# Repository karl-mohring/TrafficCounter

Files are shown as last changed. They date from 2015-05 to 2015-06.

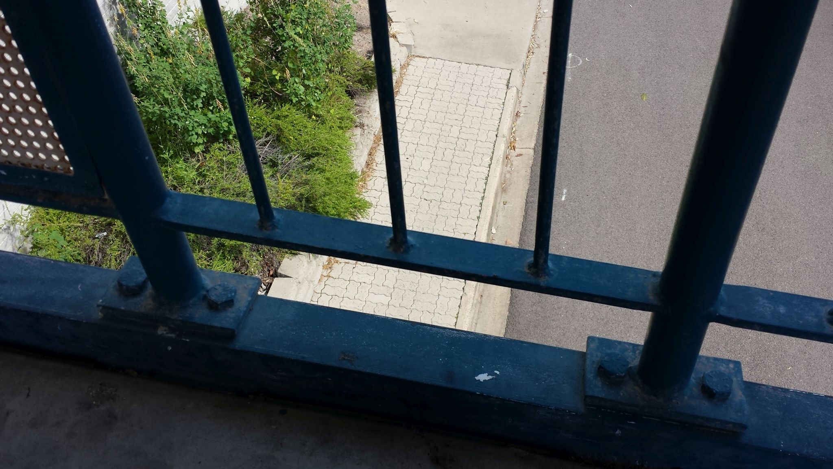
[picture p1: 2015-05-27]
CAD/Railing - 2015-05-19 11.09.42.jpg

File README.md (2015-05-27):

# TrafficCounter
Non-invasive traffic counter testbed for vehicular and pedestrian traffic. 
The testbed uses the Arduino platform, combined with low-cost and commonly available off-the-shelf sensors for ubiquitous traffic counting and classification for use inside Smart LED street lights. 

# Folders
##root
Contains the working code of the testbed, which is currently operating on the [WBoard Pro](http://imall.iteadstudio.com/im141125005.html). Functionally, the WBoard Pro is just an Arduino Mega, so either board will do. Or just change the pin assignments; what do I care?

##CAD
Graphical plans and 3D print files for mounting brackets and other peculiarities. 

##Libraries
Arduino Code libraries. What were you expecting?

##Pre-deployment Checks
Test code to check that each of the traffic sensors are functioning and calibrated before a recorded test or session.

##Tests
Test reports, recorded data, and archived code of platform deployments.

##Traffic Sink
Contains a Python script for data ingestion and uploading to Thingspeak. Change the API key in traffic_count_settings.py to suit your needs. My data is messy enough without other people injecting their own data...

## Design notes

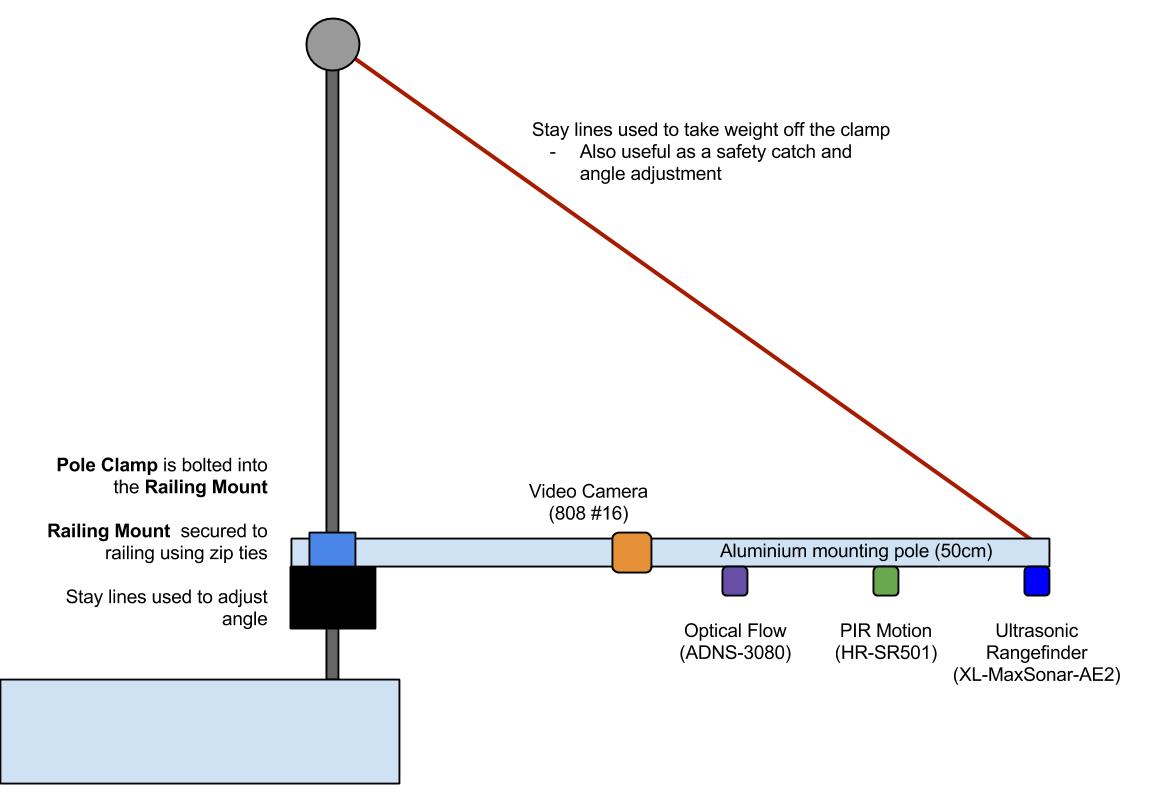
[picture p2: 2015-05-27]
CAD/TrafficCounter - Pole mounting.jpg

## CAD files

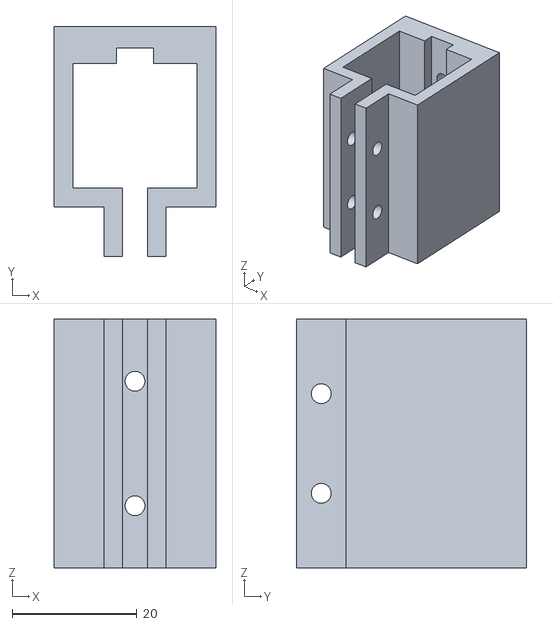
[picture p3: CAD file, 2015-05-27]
CAD/Pole clamp/Desk clamp - holder.stl
26.0 x 37.0 x 40.0

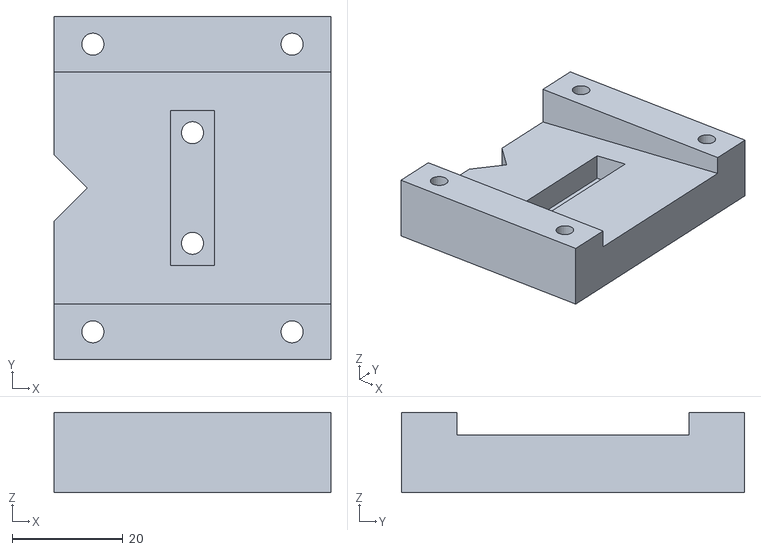
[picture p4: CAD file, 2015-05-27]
CAD/Railing Mount/Pole mount topv3 - Skewed.stl
50.0 x 62.0 x 14.5

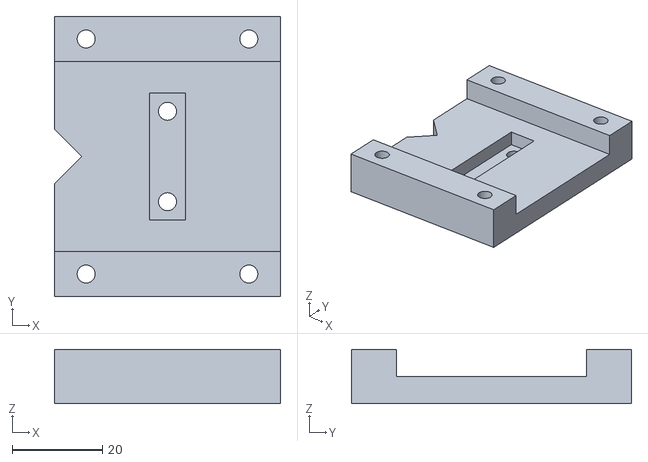
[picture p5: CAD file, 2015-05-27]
CAD/Railing Mount/Pole mount top.stl
50.0 x 62.0 x 12.0

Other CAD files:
CAD/Railing Mount/Pole mount top.skp
CAD/Railing Mount/Pole mount topv2.skp
CAD/Railing Mount/Pole mount topv3 - Skewed.skp

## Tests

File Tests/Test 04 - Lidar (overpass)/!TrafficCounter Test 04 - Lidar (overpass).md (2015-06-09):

Traffic Counter Testbed - 4th Test

Intro
=====

Aims
----

1) Test the new Lidar sensor to see if it more stable and accurate compared to the ultrasonic rangefinder (historically)

2) Test the new narrow-beam ultrasonic sensor 

Methodology
===========

Sensors
-------

- Ultrasonic rangefinder (Maxbotix XL-Maxsonar-AE2 1320)
- PIR motion sensor (HC-SR501)
- Optical flow sensor (ADNS3080)
- Keychain camera (808 #16)

Data recorder
-------------

- The ultrasonic, optical flow, and PIR sensors are periodically sampled by the WBoard Pro (Mega 2560) at a rate of 10Hz, 5Hz, and 1Hz respectively
- The keychain camera recorded constant video at a rate of 10 fps, with hard timestamps
- Whenever a traffic event is detected, all tracked data, including traffic counts from each of the sensors, sensor detection states, and other information is packaged and transferred across the USB serial link to the laptop, which is running a datalogger script
- The datalogger script adds a timestamp to each received entry and transfers the data into a log file
- Data entries are also uploaded to the Thingspeak service for real-time data monitoring over the web
- No local data storage occurs on the microcontroller board

Test location
-------------

- The second traffic sensing test was located at the pedestrian overpass outside building 34
- Sensors were secured inside a plastic container, which was then fixed to the railing directly above divide between the pedestrian footpath and roadway
- The container was angled so the sensors would be facing straight down into the roadway
- The container was secured at foot-level
- A nearby laptop was connected via USB to provide power to the sensors and also gather data for the duration of the test

Pre-Flight Checks
-----------------

Lidar
 - Baseline range of 518cm to the ground
 - No problems, seemed to detect just fine with a hand 30cm away from the sensor

OF
 - Sensor is now auto-adjusting to changes in light
 - can clearly see hand in frame from 50cm away
 - Motion not registered by sensor, but can see image at least...

Sonar
 - Baseline range of 626cm from the ground
 - readings are very twitchy, causing constant false detections
 - Readings appear to be defaulting to 626, rather than a baseline
 - Sensor is now operating off 3V3, which may be affecting its range

PIR
- Seems to be operating fine
- Hand gives a positive detection from 30cm away
-

Test Procedure
---------

1) The sensor container was secured to the outside railing of the pedestrian overpass
2) Power was supplied to the key chain camera using the laptop's USB port, and recording started well in advance of the sensor platform being turned on
3) Sensors were powered on and checked for reasonable input
4) Any necessary adjustments were applied before starting the datalogger script
- The optical flow sensor wiring became loose while securing the sensor platform to the railing and caused data to stop being transmitted by the sensor
    + The loose wire was secured at a fixed angle, which fixed the issue
- Took the lens cap off the optical flow sensor...
- The ultrasonic rangefinder was angled at various degrees to confirm readings were updating

Data Analysis
-------------

Results & Analysis
==================

Conclusions & Recommendations
=============================

UVD
---

PIR
---

Optical Flow
------------

Lidar
-----------------------

- Detection circle on ground appears to be a zone of 4cm radius
- Circle is not directly underneath the sensor, appearing approx. 1m to the right when looking down onto the road
- With a theoretical FOV of 3°, the detection circle should be approx. 25cm wide. 
- The detection circle is about right

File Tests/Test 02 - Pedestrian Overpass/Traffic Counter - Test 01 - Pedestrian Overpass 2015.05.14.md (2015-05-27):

Intro
=====

The second traffic counting test used various low-cost sensors to count both vehicular and pedestrian traffic in real time.

Aims
----
1) Test the ultrasonic rangefinder sensor in an open environment away from walls
2) Test the ultrasonic rangefinder with vehicular detection as well as pedestrian detection
3) Confirm or deny the functionality of optical flow sensing for traffic detection
4) Confirm that the PIR motion sensor was not suitable in outdoor environments

Methodology
===========

Sensors
-------

- Ultrasonic rangefinder (Maxbotix XL-Maxsonar-EZ2 1320)
- PIR motion sensor (DFRobotics PIR AM412)
- Optical flow sensor (ADNS3080)
- Keychain camera (808 #16)

Data recorder
-------------

- The ultrasonic, optical flow, and PIR sensors are periodically sampled by the WBoard Pro (Mega 2560) at a rate of 10Hz, 5Hz, and 1Hz respectively
- The keychain camera recorded constant video at a rate of 10 fps, with hard timestamps
- Whenever a traffic event is detected, all tracked data, including traffic counts from each of the sensors, sensor detection states, and other information is packaged and transferred across the USB serial link to the laptop, which is running a datalogger script
- The datalogger script adds a timestamp to each received entry and transfers the data into a log file
- Data entries are also uploaded to the Thingspeak service for real-time data monitoring over the web
- No local data storage occurs on the microcontroller board

Test location
-------------

- The second traffic sensing test was located at the pedestrian overpass outside building 34
- Sensors were secured inside a plastic container, which was then fixed to the railing directly above divide between the pedestrian footpath and roadway
- The container was angled so the sensors would be facing straight down into the roadway
- The container was secured at foot-level
- A nearby laptop was connected via USB to provide power to the sensors and also gather data for the duration of the test

Procedure
---------

1) The sensor container was secured to the outside railing of the pedestrian overpass
2) Power was supplied to the key chain camera using the laptop's USB port, and recording started well in advance of the sensor platform being turned on
3) Sensors were powered on and checked for reasonable input
4) Any necessary adjustments were applied before starting the datalogger script
- The optical flow sensor wiring became loose while securing the sensor platform to the railing and caused data to stop being transmitted by the sensor
    + The loose wire was secured at a fixed angle, which fixed the issue
- Took the lens cap off the optical flow sensor...
- The ultrasonic rangefinder was angled at various degrees to confirm readings were updating

5) Data was recorded and uploaded to Thingspeak using the datalogger script on the laptop
6) Recorded data was reviewed at the end of the test, with the option of using the recorded video feed to confirm numbers
 
Results & Analysis
==================

- Start time - 13:39:43
- Finish time- 15:14:21

- Running time - 1 hour 35 minutes

UVD
---

The ultrasonic sensor did not detect any pedestrians or vehicles at all during the test, and consistently returned a target distance between 60 cm and 90 cm. Despite a large volume of people walking underneath the sensor during the test, no events were registered by the sensor.

- The height of the pedestrian overpass is approximately 4 m above the road surface, meaning the sensor readings are clearly not accurate.
- The ultrasonic ping may be reflecting off the side of the overpass and giving false readings

PIR
---

Unlike the other sensors, the motion sensor recording an extremely high number of traffic events (1103 in total). The sensor was detecting movement when no pedestrians or vehicles were on the road.

- The sensor is much too sensitive for outdoor environments, where small changes are constantly occurring 

Optical flow
------------

No traffic events were detected by the optical flow sensor.

- The loose wiring is a concern and a possible cause for the optical flow sensor not detecting any events
- Optical flow operates on the basis that the entire frame moves a fixed amount. A single object moving across a fixed frame may not trigger the motion detection algorithm

Conclusions & Recommendations
=============================

UVD
---

The ultrasonic rangefinder is giving false readings, likely as a result of the ultrasonic ping reflecting off the bridge prematurely, instead of reflecting off the road surface. 
- A rangefinder with a narrow beam width (EZ4) may be used to replace the current sensor (that uses a medium beam width EZ2). 
- A second recommendation is to physically move the ultrasonic sensor further out and away from the edge of the overpass to avoid any reflected signals

> Order a Maxbotix XL-Maxsonar-EZ4 for further testing
> Determine the beam width of the ping on the ground for the next test
> Build a mounting arm for further tests on the overpass

PIR
---

For the second time, the motion sensor has given readings far higher than the number of actual traffic events. Motion detection is still a feasible method of traffic detection, but the sensor used in this test is far too sensitive to small changes in the environment to be of any use.
- Even in indoor environments, very small movements cause detection events.
- This particular PIR sensor does not have a configurable sensitivity. Replace the sensor with something that can be configured.

> Order a SE-10 or other PIR with configurable sensitivity and hardware timeout
> The sensor will need to be calibrated for outdoor environments

Optical Flow
------------

No traffic events were recorded by the sensor, despite having a clear view of the street below in full daylight. Connection problems may have caused the sensor to become unresponsive. Otherwise, the type of sensing performed by the sensor may not be suited to tracking the movement of individual objects.
The individual pixels of the sensor can be extracted to perform analysis on the raw data, but that would take more time than we have.
- Perform a connection check each time the sensor is read to ensure the reading is valid or if problems are occurring 
- The sensor should be re-calibrated and re-tested to ensure sensing conditions are fine

> Add code to check connectivity of the OF sensor - reflect disconnects in the data
> Perform some individual tests using the OF sensor

Further Recommendations
-----------------------

Given that no sensor has performed particularly well in the two traffic tests, it may be time to test another sensor type. Sparkfun's LIDAR lite uses laser ranging up to 40 m away. 

> Order a LIDAR from sparkfun

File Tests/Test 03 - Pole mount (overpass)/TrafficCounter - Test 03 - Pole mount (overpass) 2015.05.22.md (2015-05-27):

Traffic Counter Testbed - 3rd Test (Pole mounting)

Intro
=====

The third traffic counter test changed the mounting situation for the sensors from a shitty box to an outreach pole, not unlike those used by street light poles. A difference is that street light outreach poles aim to position the lamp closer to the centre of the roadway, while the sensor outreach pole is used to separate the traffic sensors away from any obstructions. The goals are different, but outreach poles help everyone.

Aims
----

1) Determine whether the outreach pole has fixed issues with the ultrasonic sensor
2) Run a test to ensure the optical flow sensor is actually working...
3) Test out the effectiveness of the new and adjustable PIR motion sensor

Methodology
===========

Sensors
-------

- Ultrasonic rangefinder (Maxbotix XL-Maxsonar-AE2 1320)
- PIR motion sensor (HC-SR501)
- Optical flow sensor (ADNS3080)
- Keychain camera (808 #16)

Data recorder
-------------

- The ultrasonic, optical flow, and PIR sensors are periodically sampled by the WBoard Pro (Mega 2560) at a rate of 10Hz, 5Hz, and 1Hz respectively
- The keychain camera recorded constant video at a rate of 10 fps, with hard timestamps
- Whenever a traffic event is detected, all tracked data, including traffic counts from each of the sensors, sensor detection states, and other information is packaged and transferred across the USB serial link to the laptop, which is running a datalogger script
- The datalogger script adds a timestamp to each received entry and transfers the data into a log file
- Data entries are also uploaded to the Thingspeak service for real-time data monitoring over the web
- No local data storage occurs on the microcontroller board

Test location
-------------

- The second traffic sensing test was located at the pedestrian overpass outside building 34
- Sensors were mounted to the underside of an aluminium outreach pole approximately 50cm long
- The pole was angled so the sensors would be facing straight down into the roadway
- The pole was secured at foot-level by a clamp and rope stay lines
- A nearby laptop was connected via USB to provide power to the sensors and also gather data for the duration of the test

Pre-Flight Checks
-----------------

UVD - The sensor output was checked for range to ensure the beam was not reflecting off the overpass or nearby surfaces. A manual reading was triggered by blocking the sensor with a hand

PIR - Similar to the ultrasonic sensor, the PIR sensor was manually triggered by moving a hand in front of the sensor. The PIR test does not have a cooldown timer, unlike the traffic counter firmware. Detection times and information is available in the test console.

Optical flow - To first calibrate the sensor, the RAW pixel data from the sensor is read and displayed on the laptop to ensure the frame is in focus. After calibration, the sensor's motion register is polled to check if motion has been detected by the sensor.

Procedure
---------

1) The sensor pole was secured to the outside railing of the pedestrian overpass
2) Power was supplied to the key chain camera using the laptop's USB port, and recording started well in advance of the sensor platform being turned on
3) Sensors were powered on and checked for reasonable input
4) Any necessary adjustments were applied before starting the datalogger script
- The optical flow sensor wiring became loose while securing the sensor platform to the railing and caused data to stop being transmitted by the sensor
    + The loose wire was secured at a fixed angle, which fixed the issue
- Took the lens cap off the optical flow sensor...
- The ultrasonic rangefinder was angled at various degrees to confirm readings were updating

5) Data was recorded and uploaded to Thingspeak using the datalogger script on the laptop

Data Analysis
-------------

1) Video data was reviewed to gain a comprehensive list of traffic information, including event times, traffic type (pedestrian, cyclist, vehicle), and whether or not a multiple event is occurring.
2) Count data was compared graphically between the actual video count and the other sensors, specifically:
    - PIR vs All traffic events (events; multiple events counted as one)
    - UVD vs Actual Vehicle traffic
    - New PIR events vs all traffic events (run-on events discarded)

Results & Analysis
==================

Over the course of the test, the video camera recorded a total of 50 combined traffic events (5 vehicles, 47 pedestrians, 5 cyclists, 1 scrub turkey). 

While the camera was focussed on the main detection area, the mounting and lens characteristics may mean that some events picked up the PIR sensor may not have been 'seen' by the camera.

UVD (and pole mount)
--------------------

Both during the pre-deployment check, and throughout the test, the ultrasonic rangefinder registered a baseline target distance of 792cm. While the range is likely not accurate (and beyond the sensors maximum rated range of 745cm), the ping does not appear to be reflecting off of the overpass edge. Range readings were less consistent in this test compared to previous deployments, as several pings were not returned, causing the range to read as 1024cm. 

During the pre-deployment check, several pedestrians walked underneath the sensor, but were not detected. However, a car driving on the road below was able to cause a detection to occur, but only on the incoming direction. The sensor did not detect the same car travelling in the opposite direction.

The ultrasonic sensor was not able to detect any pedestrian or cyclist traffic events during the recorded test, and only seemed to trigger when cars were on the road. Counting only vehicles, the UVD appeared to detect 3 of 5 vehicle events (not including the detection in the pre-deployment check) when compared to the video footage. The failed detection may be due to the sensor field of view looking at the footpath-road junction, rather than direction down onto the road, meaning the missing traffic events may have just been out of view of the sensor. 

The three positive vehicle detections by the ultrasonic rangefinder appear to occur a consistent 40 seconds before a vehicle detection event from the video, meaning there is likely a 40 second clock offset between the video camera, and the recording laptop.

1st vehicle - Not detected - Car was on the edge of the camera range, likely outside of the ultrasonic sensor detection area, cannot see roof in video

2nd vehicle - Detected - JCU buggy - reasonably close to the curb, large flat and high roof would assist detection

3rd vehicle - Detected - Sedan - reasonably close to curb, about the same as the buggy - hard to tell actual distances due to lens distortion

4th vehicle - Not detected - Far away from curb, cannot see roof in the video

5th vehicle - Detected - roof clearly visible from video, very close to the curb 

Vehicle detections caused the sensor to read range values from 532cm to 644cm, meaning car heights would have been 257cm and 144cm respectively. A vehicle height of 257cm is not entirely unreasonable for a 4wd or otherwise large vehicle, but only small sedans were observed during the test. The 144cm height is perfectly reasonable for the small cars observed during the test, which would indicate that cars were indeed being detected by the ultrasonic rangefinder. 

PIR
---

The PIR sensor performed as expected during the pre-deployment checks with the sensor firing only when a hand was moved in front of the sensor. Positive pedestrian detections occurred during the sensor check. The hardware motion cooldown reset after approximately 1.8 seconds. 

The software cooldown for the PIR sensor was set to reset after 2 seconds; not long after the hardware cooldown. The result of this low cooldown time is a large number of run-on events, where targets took longer than the cooldown time to cross the field of view, resulting in multiple traffic events being registered for the same target. Overall, 109 traffic events were captured by the PIR sensor, covering all types of traffic (the sensor is unable to distinguish between traffic types). A significant amount of these events were run-on motion events, where the motion event is still running even after the cooldown period has elapsed. The occurrance of run-on events is not surprising, considering pedestrians can take over 6 seconds to walk across the detection area, giving plenty of time for the sensor to trigger multiple times and causing an inflated traffic count. A workaround to eliminate these duplicate events was to discard traffic events where the previous sensor state was high (indicating a running detection event). Comparison of only 'new' detection events and video events showed a very high correlation between count timelines, as well as a very close total count (54 for PIR vs 50 for video).

Detection counts between PIR and video have very similar counts and times. The counts seem to diverge at points where multiple traffic events occur at once, indicating the PIR sensor may still be triggering twice for multiple events.

Very close (but separate) traffic events can be counted with video processing that cannot be detected by the PIR sensor because of its cooldown period.

The PIR count was consistently higher than the number of video events (apart from the start of the test), but also consistently lower than the actual traffic count (total number of pedestrians, cyclists, and vehicles)

Optical Flow
------------
 
 During the calibration for the optical flow sensor, the entire raw pixel data showed an entirely white frame that would only change when all light into the lens was blocked. Even the smallest amount of light would cause the sensor to completely white out. Changing the focal point of the lens did not affect the white-out. As this sensor has been used for outdoor navigation on multicopters, the sensor is clearly capable of outdoor usage, meaning the white-balance issues must be solvable.

 Furthermore, the sensor test, which is triggered by moving the entire sensor arm up, did not produce any motion detections. 

 While the sensor registered as "connected" during the pre-deployment check, the connection status changed to "disconnected" for the entirety of the recording period. Further checks in the lab with the same code did not experience this same sensor drop out.

Conclusions & Recommendations
=============================

UVD (and pole mount)
--------------------

Moving to the pole-mounted sensor deployment helped greatly in setting up and packing away sensors quickly and easily, allowing for consistent angling and overhang distance away from the side of the overpass. More importantly, the 40cm pole allowed for enough clearance for the ultrasonic rangefinder. Both in tethered and untethered tests (pole held out over road manually), moving the rangefinder away from the wall provided consistently and much more accurate readings. 

One possible issue with the current deployment setup is that the overpass is not level, and actually slopes at a 5° angle, meaning ultrasonic pings directed down towards the road will not hit and reflect perpendicularly. 
>The mounting bracket should be altered to correct for this slight angle.

The ultrasonic sensor was not able to detect any pedestrians during this test, but all detections occurred when a vehicle was on the road below, indicating that the rangefinder is able to detect vehicular traffic. However, vehicle detections only registered on the sensor when the car was very close to the road, almost directly under the sensor. 
>As the PIR sensor can detect movement over a wide area, the traffic counter should be placed closer to the middle of the road way to allow the ultrasonic sensor to detect traffic more accurately, while still allowing the PIR sensor to detect pedestrian traffic on the footpath.

The nature of ultrasonic sensor make the detection areas fairly unclear. 
>A buzzer should be added to the testbed to allow for rapid feedback on each of the sensors. Exact detection bounds can then be identified so the detection areas can be physically mapped out on the ground below for each of the sensors, and also picked up by the video footage. 

PIR
---

At the lowest sensitivity and shortest hardware cooldown, the PIR sensor was able to detect traffic events of all types with a great degree of accuracy (8% overshoot). However, the short sensor cooldown meant that many traffic events were counted twice. 
>The PIR cooldown time should be changed to more closely resemble the time it takes for a pedestrian to cross the detection boundaries for more accurate traffic counts.

Alternatively, only new traffic events should be counted to eliminate possible run-on events.

Optical Flow
------------
>Look into the datasheet to see if there's a way to fix the white balance, as the sensor is not currently able to output any useful data.

The optical flow sensor is not suitable at detecting motion in a fixed scenario, as the sensor operates by calculating movement over the entirety of the image, rather than individual objects moving through the frame. However, the raw output of the sensor allows for video image processing techniques to be used at a very low computational cost. The 900 pixel count is unsuitable for facial identification (which is a plus in this scenario), but is capable if identifying multiple objects at once, and categorising different moving objects, and calculating their approximate speed.

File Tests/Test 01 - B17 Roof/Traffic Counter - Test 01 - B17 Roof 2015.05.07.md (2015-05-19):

Intro
=====

The traffic counter test was used to test the accuracy of two sensors for non-invasive traffic detection. Ultrasonic vehicle detection uses the distance between the sensor and a distance target to determine whether or not traffic event is occurring. Normally, this distance will be from the sensor to the road surface if the sensor is deployed in an overhead position. Cars or pedestrians underneath will cause the sensor to register a shorter distance between the sensor and its target. This way, the sensor can determine the presence of an object in the beam path, and motion can be calculated using successive readings.

The second sensor uses Passive Infrared to monitor the surrounding environment and determine if any movement has occurred. All objects with temperatures above absolute zero radiate infrared energy that can be picked up the a sensor. The PIR sensor takes a snapshot of the surrounding area and checks for changes in infrared radiation. Any changes between snapshots indicate that something has moved.

Aim
---

1) Determine whether or not the ultrasonic rangefinder could be used to count pedestrian traffic when mounted at streetlight level
2) Determine whether or not the PIR sensor could be used to count pedestrian traffic when mounted at streetlight level

Methodology
===========

Sensors
-------

- Ultrasonic rangefinder (Maxbotix XL-Maxsonar-EZ2 1320)
- PIR motion sensor (DFRobotics PIR AM412)
- Keychain camera (808 #16)

Data recorder
-------------

- Both ultrasonic and PIR sensors were periodically sampled by the WBoard Pro (Mega 2560) at a rate of 5 Hz and 1 Hz respectively. The low sample rate with the PIR sensor is due to its long motion timeout of 3 seconds. That is, any movement picked up by the sensor would cause the device to advertise motion for 3 seconds.
- The keychain camera recorded constant video at a rate of 10 fps, with hard timestamps
- Traffic counts from each of the sensors was monitored and kept in local memory
- Data was written to an integrated SD card every 5 seconds
- The running sensor data was also transmitted to a nearby base station using an XBee transceiver
- The base station kept a log file of all received transmissions and uploaded the entries to a Thingspeak channel for monitoring over the web

Test location
-------------

- The sensor box was mounted on the roof of Building 17, on a pole overlooking the side entrance of the building
- Both sensors and the camera were pointed to capture the middle of the walkway (slightly off straight down)
- Power was supplied using a USB charger connected to a nearby power outlet on the roof of Building 17

Procedure
---------

1) The sensors and camera were secured at a fixed angle inside a container
2) The container was then secured to the mounting pole, then adjusted to achieve the desired angle
3) Power was switched on to the camera and microcontroller board to start sensor calibration and data recording
4) The nearby base station started receiving data soon afterwards and uploading the data online.

5) The sensors were left to record over the next 2 hours and 28 minutes
6) After the recording session, traffic events were mapped into time periods.
7) Actual pedestrian numbers were determined by reviewing the recorded video footage and mapped into the same time periods
8) Traffic counts, as well as event times were compared between the ultrasonic rangefinder, PIR sensor, and the video recording.

Results and Analysis
--------------------

Video
-----

Manually reviewing the recorded video footage revealed that a total of 80 people entered or exited the building over the couse of the test over 75 traffic events (some were double events). 
- Visual confirmation of traffic events was extremly valuable in gaining an accurate number of detection, as well as timestamps
- Video analysis also made double detections possible where other sensing methods may not perform as well
- The video was recorded to an onboard SD card, which allows the camera to be compact, but video can only be reviewed after recording has finished.
- Also, the video footage needed to be reviewed manually, which takes time and is prone to human error. Several video image processing programs exist for pedestrian and vehicle detection, but require more processing power that what is available in the test platform.

> Continue using manual video review for accurate traffic event coints

UVD
---

Over the course of the test, the ultrasonic sensor recorded 61 events. The ultrasonic and PIR traffic data did not have access to a real-time clock, meaning mapping needed to be approximated using base station timestamps and video events.
A direct comparison between the video counts and the ultrasonic detections shows a correlation between the two systems that diverges at the end. However, the correlation may be a result of erroneous range measurements.
According to the rangefinder, the sensor is located approximately 660 cm above the ground, which is not as high as expected. The beam may be reflecting off something on the wall.
- The ultrasonic rangefinder detected 61 individual traffic events, which is similar to the actual 75 events (61/75 events = 81.3% accuracy)
- While the count is similar, there is only a loose correlation between the video detection times and the ultrasonic detection times. Granted, there is an uncertainty in the timing offset between the video and the sensor data. Some ultrasonic detections appear entirely random, with no visible events that could trigger the sensor. Similarly, there are several traffic events that occur on video that are not detected by the ultrasonic sensor.
- At this point in time, there is no way of knowing whether the detections reported by the ultrasonic sensor are genuine or cause by erroneous readings, especially when the baseline height of the sensor is suspiciously low
- Another thing to consider is that the ultrasonic rangefinder was not inteded for pedestrian sensing, as the low cross-sectional area of pedestrians from an overhead perspective is low. Cars and other road vehicle exhibit a much larger cross-sectional area, which makes them more likely to be detected by the ultrasonic detector.

> Look for a better testing space for traffic testing

PIR
---

The PIR motion sensor detected 723 traffic events over the duration of the test, which was well in excess of the 75 actual events counted by the video footage. 
- While the sensor behaves as expected in an indoor lab condition, with motion alarms being triggered when objects are moving across the sensors field of view, the sensor behaves drastically different in outdoor environments. The sensitivity of the sensor caused the motion alarm to fire much more often. 
- One possibility is that small changes in lighting, such as those cast by shadows of surrounding vegetation, may have triggered the sensor to detect an event
- Another possible cause of the sensor's high detection rate is the altered lighting conditions compared to a lab environment. Direct sunlight is much brighter than indoor lighting. Perhaps there are peculiarities with this particular sensor and direct sunlight.

> Try the sensor again in a different location
> Find another PIR motion detector with an adustable sensitivity, so outdoor noise can be filtered
> Search the sensor's datasheet to see if there are and usage instructions for outdoor environments

Conclusions & Recommendations
=============================

Video
-----

Video monitoring proved to be extremely useful for counting traffic to verify the numbers presented by the other sensors. However, automating the footage review process is computationally intensive, and cannot be performed by the sensor platform hardware. Video image processing should still be used in the field of testing, but cannot be used for actual traffic sensing without using a much more powerful processor to handle the computational load.

UVD
---

The sensor output needs to be confirmed as correct through more testing.
Another testing location may be needed to better replicate the conditions found on streetlights with open spaces away from wall surfaces. 

PIR
---

Although the final traffic count registered b the motion sensor far exceeded the actual number of traffic events, motion sensing has been used by many pedestrian sensing effors in the past. Adjustable sensitivity, as well as appropriate lensing may be needed to handle the imitations that PIR sensors face when deployed in outdoor environments.

This test was the first outdoor deployment of the traffic sensor suite. The location, while not necessarily typical of a street light deployment, presented many challenges that would be present in an outdoor environment, including large nearby surfaces, and constantly changing environments.

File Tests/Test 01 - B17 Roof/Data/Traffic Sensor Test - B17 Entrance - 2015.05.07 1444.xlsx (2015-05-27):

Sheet: RAW
Traffic |  | counter
Rangefinder |  | baseline | 661 | cm | Variance | 0cm
************
 | count_uvd | 3 | count_pir | 1 | range | 32 | pir_status | FALSE | time | 13316 | entry_num | 1
 | count_uvd | 3 | count_pir | 2 | range | 662 | pir_status | TRUE | time | 18316 | entry_num | 2
 | count_uvd | 3 | count_pir | 3 | range | 662 | pir_status | TRUE | time | 23316 | entry_num | 3
 | count_uvd | 3 | count_pir | 4 | range | 664 | pir_status | TRUE | time | 28316 | entry_num | 4
 | count_uvd | 3 | count_pir | 5 | range | 664 | pir_status | FALSE | time | 33316 | entry_num | 5
 | count_uvd | 7 | count_pir | 5 | range | 662 | pir_status | FALSE | time | 38316 | entry_num | 6
 | count_uvd | 8 | count_pir | 5 | range | 97 | pir_status | FALSE | time | 44050 | entry_num | 7
 | count_uvd | 11 | count_pir | 6 | range | 134 | pir_status | TRUE | time | 48316 | entry_num | 8
 | count_uvd | 12 | count_pir | 6 | range | 661 | pir_status | FALSE | time | 53316 | entry_num | 9
 | count_uvd | 14 | count_pir | 6 | range | 790 | pir_status | FALSE | time | 58316 | entry_num | 10
 | count_uvd | 16 | count_pir | 7 | range | 662 | pir_status | TRUE | time | 63316 | entry_num | 11
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

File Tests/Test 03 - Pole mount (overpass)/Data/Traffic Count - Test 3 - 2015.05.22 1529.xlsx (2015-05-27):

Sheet: RAW
2015-05-22 | 15:29:20 | 503 | - | ERROR | - | Serial | port | [COM5] | cannot | be | opened | :(
2015-05-22 | 15:30:23 | 414 | - | ERROR | - | Serial | port | [COM3] | cannot | be | opened | :(
2015-05-22 | 15:30:39 | 168 | - | INFO | - | Incoming | packet: | u'count_pir': | 0 | u'of_dy': | 0 | u'count_uvd': | 0 | u'of_dx': | 0 | u'count_of': | 0 | u'range': | 787 | u'version': | 2 | u'of_status': | FALSE | u'pir_status': | FALSE | u'id': | u'trafficCount' | u'of_connected': | False}
2015-05-22 | 15:31:22 | 142 | - | INFO | - | Incoming | packet: | u'count_pir': | 1 | u'of_dy': | 0 | u'count_uvd': | 0 | u'of_dx': | 0 | u'count_of': | 0 | u'range': | 788 | u'version': | 2 | u'of_status': | FALSE | u'pir_status': | FALSE | u'id': | u'trafficCount' | u'of_connected': | True}
2015-05-22 | 15:31:25 | 171 | - | INFO | - | Incoming | packet: | u'count_pir': | 2 | u'of_dy': | 0 | u'count_uvd': | 0 | u'of_dx': | 0 | u'count_of': | 0 | u'range': | 782 | u'version': | 2 | u'of_status': | FALSE | u'pir_status': | TRUE | u'id': | u'trafficCount' | u'of_connected': | True}
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

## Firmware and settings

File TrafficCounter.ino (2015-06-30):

#include <LIDARduino.h>
#include <ADNS3080.h>
#include <SPI\SPI.h>
#include <ProgmemString.h>
#include <StraightBuffer.h>
#include <Logging.h>
#include <JsonParser.h>
#include <JsonGenerator.h>
#include <Maxbotix.h>
#include <SimpleTimer.h>
#include <CommandHandler.h>

#include "config.h"

using namespace ArduinoJson::Generator;

const int TRAFFIC_COUNTER_VERSION = 5;

//////////////////////////////////////////////////////////////////////////
// Traffic Counter
// 
// Uses non-invasive sensors to count vehicular and pedestrian traffic 
// from a distance. 
//
//////////////////////////////////////////////////////////////////////////


//////////////////////////////////////////////////////////////////////////
// Config


// Rangefinder
Maxbotix rangeSensor(RANGEFINDER_AN_PIN, Maxbotix::AN, Maxbotix::XL);
int rangeBaseline;

// Lidar
LIDAR_Lite_PWM lidar(LIDAR_TRIGGER_PIN, LIDAR_DETECT_PIN);
int lidarBaselineRange;

// PIR motion
bool motionDetected;
long timeOfLastMotion;

// Optical Flow
AP_OpticalFlow_ADNS3080 flowSensor(OPTICAL_FLOW_CHIP_SELECT_PIN, 0);
int8_t flow_dx;
int8_t flow_dy;

// Timers
SimpleTimer timer;
int rangeTimerID = -1;
int motionTimerID = -1;
int flowTimerID = -1;
int lidarTimerID = -1;

// Buzzer stuff
int beepCount = 0;
int maxBeeps = 0;

// Data storage
JsonObject<13> trafficEntry;
StraightBuffer sendBuffer(SEND_BUFFER_SIZE);

// Serial commands
char _commandCache[COMMAND_CACHE_SIZE];
CommandHandler commandHandler(_commandCache, COMMAND_CACHE_SIZE);

long entryNumber;
bool linuxBusy;


//////////////////////////////////////////////////////////////////////////
// Arduino Functions
//////////////////////////////////////////////////////////////////////////

/**
* Startup code - Run once
*/
void setup()
{
	startYunSerial();
	Log.Info(P("Traffic Counter - ver %d"), TRAFFIC_COUNTER_VERSION);

	// Start up sensors
	startBuzzer();
	startSensors();
	addSerialCommands();

}

/**
* Main loop - run forever
*/
void loop()
{
	timer.run();
	checkSerial();
}


//////////////////////////////////////////////////////////////////////////
// User Functions
//////////////////////////////////////////////////////////////////////////

//////////////////////////////////////////////////////////////////////////
// Yun Serial

/**
* Set up the Arduino-Linux serial bridge
* Serial output from the Arduino is disabled until the Yun has finished booting
*/
void startYunSerial(){

	// Set up the handshake pin
	pinMode(YUN_HANDSHAKE_PIN, INPUT_PULLUP);
	pinMode(LED_BUILTIN, OUTPUT);

	// Check the initial state of the handshake pin (LOW == Ready)
	delay(YUN_BOOT_DELAY);
	_bootStatusChange();

	Serial1.begin(SERIAL_BAUD);

	// Listen on the handshake pin for any changes
	attachInterrupt(4, _bootStatusChange, CHANGE);
}

/**
* Check the boot status of the Yun
*/
void _bootStatusChange(){
	linuxBusy = digitalRead(YUN_HANDSHAKE_PIN);
	digitalWrite(LED_BUILTIN, linuxBusy);

	// Disable log output until Linux boots
	if (linuxBusy){
		Log.Init(LOG_LEVEL_NOOUTPUT, &Serial1);
	}
	else{
		Log.Init(LOGGER_LEVEL, &Serial1);
	}
}

/**
* Enable and configure the sensor suite for reading
*/
void startSensors(){
	trafficEntry[ID] = "trafficCount";
	trafficEntry[VERSION] = TRAFFIC_COUNTER_VERSION;

	trafficEntry[COUNT_UVD] = 0;
	trafficEntry[UVD_RANGE] = 0;

	trafficEntry[COUNT_PIR] = 0;
	trafficEntry[PIR_STATUS] = false;

	trafficEntry[COUNT_OF] = 0;
	trafficEntry[OF_X_OFFSET] = 0;
	trafficEntry[OF_Y_OFFSET] = 0;
	trafficEntry[OF_STATUS] = false;
	trafficEntry[OF_CONNECTED] = false;

	trafficEntry[COUNT_LIDAR] = 0;
	trafficEntry[LIDAR_RANGE] = 0;

	startRangefinder();
	startLidar();
	startMotionDetector();
	startOpticalFlow();
}

/**
* Check serial comms for incoming commands
*/
void checkSerial(){
	while (Serial.available()){
		char inChar = Serial.read();
		commandHandler.readIn(inChar);
	}
}

/**
* Add commands to the response list
*/
void addSerialCommands(){
	commandHandler.setTerminator(COMMAND_TERMINATOR);

	commandHandler.addCommand(RESET_UVD_COUNT, resetRangeCount);
	commandHandler.addCommand(DISABLE_UVD, startRangefinder);
	commandHandler.addCommand(ENABLE_UVD, stopRangefinder);

	commandHandler.setDefaultHandler(defaultHandler);
}

/**
* Bad command received. Make fun of the sender
*/
void defaultHandler(char c){
	Log.Error(P("Command not recognised: %s"), c);
}

/**
* Print the current traffic counts and info to Serial
*/
void printData(){
	if (!linuxBusy){
		Serial1.print("#");
		trafficEntry.printTo(Serial1);
		Serial1.println("$");
	}
}


//////////////////////////////////////////////////////////////////////////
// Rangefinder

/**
* Start the rangefinder sensor
*
* A baseline range (to the ground or static surrounds) is established for
* comparing against new measuremets.
*
*/
void startRangefinder(){

	// Configure control pint
	enableRangefinder();

	Log.Debug(P("Ultrasonic - Establishing baseline range..."));
	rangeBaseline = getRangefinderBaseline(BASELINE_VARIANCE_THRESHOLD);

	Log.Debug(P("Ultrasonic Baseline established: %d cm, %d cm variance"), rangeBaseline, BASELINE_VARIANCE_THRESHOLD);
	trafficEntry[UVD_RANGE] = rangeBaseline;
	printData();

	rangeTimerID = timer.setInterval(CHECK_RANGE_INTERVAL, checkRange);
}

/**
* Establish the baseline range from the sensor to the ground
* The sensor will take samples until the readings are consistent
*/
int getRangefinderBaseline(int variance){
	// Establish baseline (fixed height) of the range sensor
	int averageRange = getRange();
	int baselineReads = 1;
	int averageVariance = 500;

	// Keep reading in the baseline until it stablises
	while (baselineReads < MIN_BASELINE_READS || averageVariance > variance){
		int newRange = getRange();
		int newVariance = (averageRange - newRange);
		if (newVariance < 0){ newVariance *= -1; }

		averageVariance = ((averageVariance + newVariance) / 2);
		averageRange = ((averageRange + newRange) / 2);

		Log.Debug(P("Ultrasonic Calibration: Range - %d, Variance - %d"), int(averageRange), averageVariance);

		baselineReads++;
		delay(BASELINE_READ_INTERVAL);
	}

	return averageRange;
}

/**
* Stop reading the ultrasonic range data and disable the sensor
*/
void stopRangefinder(){
	disableRangefinder();
	timer.deleteTimer(rangeTimerID);
}

/**
* Allow the ultrasonic rangefinder to send ping signals
*/
void enableRangefinder(){
	pinMode(RANGEFINDER_CONTROL_PIN, OUTPUT);
	digitalWrite(RANGEFINDER_CONTROL_PIN, HIGH);
}

/**
* Stop sending range pings.
*/
void disableRangefinder(){
	digitalWrite(RANGEFINDER_CONTROL_PIN, LOW);
}

/**
* Get the range in cm from the ultrasonic rangefinder
*
* @return Target distance from sensor in cm
*/
int getRange(){
	int targetDistance = rangeSensor.getRange();
	Log.Debug(P("Ultrasonic Range: %d cm"), targetDistance);
	return targetDistance;
}

/**
* Check the ultrasonic range sensor to see if a traffic event has occurred.
*
* Traffic events are counted as a break in the sensor's 'view' of the ground.
* Any object between the sensor and the ground baseline will cause the sensor
* to register a shorter range than usual.
*/
void checkRange(){
	int lastRange = trafficEntry[UVD_RANGE];
	int newRange = getRange();

	trafficEntry[UVD_RANGE] = newRange;

	// Detection occurs when target breaks the LoS to the baseline
	if ((rangeBaseline - newRange) > RANGE_DETECT_THRESHOLD && (lastRange - newRange) > RANGE_DETECT_THRESHOLD){

		// Increase traffic count
		int trafficCount = trafficEntry[COUNT_UVD];
		trafficCount++;
		trafficEntry[COUNT_UVD] = trafficCount;

		Log.Info(P("Traffic count - UVD: %d counts"), trafficCount);

		// Also send an XBee alert
		printData();
		beep(NUM_BEEPS_UVD);
	}
}

/**
* Reset the traffic count for the ultrasonic rangefinder
*/
void resetRangeCount(){
	trafficEntry[COUNT_UVD] = 0;
	Log.Info(P("Traffic count reset - UVD"));
}


//////////////////////////////////////////////////////////////////////////
// Lidar

/**
* Start the rangefinder sensor
*
* A baseline range (to the ground or static surrounds) is established for
* comparing against new measuremets.
*
*/
void startLidar(){
	pinMode(LIDAR_TRIGGER_PIN, INPUT);
	pinMode(LIDAR_DETECT_PIN, INPUT);
	pinMode(LIDAR_CONTROL_PIN, OUTPUT);

	enableLidar();
	lidar.begin();

	Log.Debug(P("Lidar - Establishing baseline range..."));
	lidarBaselineRange = getLidarBaselineRange(BASELINE_VARIANCE_THRESHOLD);
	Log.Debug(P("Lidar Baseline established: %d cm, %d cm variance"), lidarBaselineRange, BASELINE_VARIANCE_THRESHOLD);

	lidarTimerID = timer.setInterval(LIDAR_CHECK_RANGE_INTERVAL, checkLidarRange);
}

/**
* Establish the baseline range from the lidar to the ground
* The sensor will take samples until the readings are consistent
*/
int getLidarBaselineRange(int variance){
	// Establish baseline (fixed height) of the range sensor
	int averageRange = getLidarRange();
	int baselineReads = 1;
	int averageVariance = 500;

	// Keep reading in the baseline until it stablises
	while (baselineReads < MIN_BASELINE_READS || averageVariance > variance){
		int newRange = getLidarRange();
		int newVariance = (averageRange - newRange);
		if (newVariance < 0){ newVariance *= -1; }

		averageVariance = ((averageVariance + newVariance) / 2);
		averageRange = ((averageRange + newRange) / 2);

		Log.Debug(P("Lidar Calibration: Range - %d, Variance - %d"), int(averageRange), averageVariance);

		baselineReads++;
		delay(BASELINE_READ_INTERVAL);
	}

	return averageRange;
}

/**
* Stop reading the lidar and disable the sensor
*/
void stopLidar(){
	disableLidar();
	timer.deleteTimer(lidarTimerID);
}

/**
* Allow the lidar to send ping signals
*/
void enableLidar(){
	digitalWrite(LIDAR_CONTROL_PIN, HIGH);
}

/**
* Stop sending range pings.
*/
void disableLidar(){
	digitalWrite(LIDAR_CONTROL_PIN, LOW);
}

/**
* Get the range in cm from the lidar
*
* @return Target distance from sensor in cm
*/
int getLidarRange(){
	int targetDistance = lidar.getDistance();
	Log.Debug(P("Lidar Range: %d cm"), targetDistance);
	return targetDistance;
}

/**
* Check the lidar to see if a traffic event has occurred.
*
* Traffic events are counted as a break in the sensor's 'view' of the ground.
* Any object between the sensor and the ground baseline will cause the sensor
* to register a shorter range than usual.
*/
void checkLidarRange(){
	int lastRange = trafficEntry[LIDAR_RANGE];
	int newRange = getLidarRange();

	trafficEntry[LIDAR_RANGE] = newRange;

	// Detection occurs when target breaks the LoS to the baseline
	if ((lidarBaselineRange - newRange) > RANGE_DETECT_THRESHOLD && (lastRange - newRange) > RANGE_DETECT_THRESHOLD){

		// Increase traffic count
		int trafficCount = trafficEntry[COUNT_LIDAR];
		trafficCount++;
		trafficEntry[COUNT_LIDAR] = trafficCount;

		Log.Info(P("Traffic count - Lidar: %d counts"), trafficCount);

		printData();
		beep(NUM_BEEPS_LIDAR);
	}
}

/**
* Reset the traffic count for the lidar
*/
void resetLidarCount(){
	trafficEntry[COUNT_LIDAR] = 0;
} 


//////////////////////////////////////////////////////////////////////////
// Motion Detector

/**
* Start the PIR motion sensor for motion detections
*/
void startMotionDetector(){
	enableMotion();

	pinMode(PIR_MOTION_PIN, INPUT);

	Log.Info(P("Calibrating motion sensor - wait %d ms"), MOTION_INITIALISATION_TIME);
	delay(MOTION_INITIALISATION_TIME);
	motionDetected = false;

	motionTimerID = timer.setInterval(CHECK_MOTION_INTERVAL, checkPirMotion);
	Log.Debug(P("Motion started"));
}

/**
* Stop checking the motion detector
*/
void stopMotionDetector(){
	timer.deleteTimer(motionTimerID);
	disableMotion();

	Log.Debug(P("Motion sensor stopped"));
}

/**
* Check the PIR sensor for detected movement
* The sensor will output HIGH when motion is detected.
* Detections will hold the detection status HIGH until the cool-down has lapsed (default: 60s)
*
* Returns:
*	True if motion has been detected recently
*/
void checkPirMotion(){

	// Check the sensor
	if (digitalRead(PIR_MOTION_PIN) == MOTION_DETECTED){

		motionDetected = true;
		Log.Info(P("Motion detected"));

		// Increment PIR count
		long motionCount = trafficEntry[COUNT_PIR];
		motionCount++;
		trafficEntry[COUNT_PIR] = motionCount;

		Log.Info(P("Traffic count - PIR: %l counts"), motionCount);

		printData();
		beep(NUM_BEEPS_PIR);

		// Enter the cooldown phase
		motionCoolDown();

	}
	else{
		// No alarm; is fine
		motionDetected = false;
	}


	trafficEntry[PIR_STATUS] = motionDetected;
}

/**
* Temporarily pause checking the PIR motion sensor
*/
void motionCoolDown(){
	timer.deleteTimer(motionTimerID);
	motionTimerID = -1;
	timer.setTimeout(MOTION_COOLDOWN, resumeMotionDetection);
}

/**
* Start polling the PIR motion sensor
*/
void resumeMotionDetection(){
	motionTimerID = timer.setInterval(CHECK_MOTION_INTERVAL, checkPirMotion);
}

/**
* Reset the number of motion detections
*/
void resetMotionCount(){
	trafficEntry[COUNT_PIR] = 0;
}

/**
* Turn the motion sensor on - in a non-sexy way
*/
void enableMotion(){
	pinMode(PIR_CONTROL_PIN, OUTPUT);
	digitalWrite(PIR_CONTROL_PIN, HIGH);
}

/**
* Turn the motion sensor off
*/
void disableMotion(){
	digitalWrite(PIR_CONTROL_PIN, LOW);
}


//////////////////////////////////////////////////////////////////////////
// Optical Flow

/**
* Start and initialise the optical flow sensor
* The connection is confirmed by polling the device's product code
*/
void startOpticalFlow(){
	flowSensor.init(true);

	Log.Debug(P("Starting optical flow sensor"));

	byte retries = 0;
	bool flowConnected;
	while (!flowConnected && retries < OPTICAL_FLOW_MAX_RETRIES){
		flowConnected = checkOpticalFlowConnection();
		Log.Debug(P("ADNS3080 connected: %T"), flowConnected);
		retries++;
	}

	if (flowConnected){
		Log.Debug(P("Optical flow connected. Configuring..."));
		trafficEntry[OF_CONNECTED] = true;

		flowSensor.set_frame_rate_auto(true);
		flowSensor.set_shutter_speed_auto(true);
		flowSensor.set_resolution(1600);
	}

	flowTimerID = timer.setInterval(CHECK_FLOW_INTERVAL, updateFlowMotion);
}

/**
* Stop monitoring the optical flow sensor
*/
void stopOpticalFlow(){
	timer.deleteTimer(flowTimerID);
	flowTimerID = -1;
}

/**
* Start monitoring the optical flow sensor
*/
void resumeOpticalFlow(){
	flowSensor.clear_motion();
	flowTimerID = timer.setInterval(CHECK_FLOW_INTERVAL, updateFlowMotion);
}

/**
* Check the optical flow sensor to see if motion has been detected
*/
void updateFlowMotion(){
	bool connected = checkOpticalFlowConnection();
	trafficEntry[OF_CONNECTED] = connected;

	if (connected){
		byte motionRegister = flowSensor.read_register(ADNS3080_MOTION);
		bool flowDetected = motionRegister & 0x80;

		trafficEntry[OF_STATUS] = flowDetected;

		// Motion detected - determine the direction
		if (flowDetected){
			int8_t of_dx = flowSensor.read_register(ADNS3080_DELTA_X);
			int8_t of_dy = flowSensor.read_register(ADNS3080_DELTA_Y);

			trafficEntry[OF_X_OFFSET] = of_dx;
			trafficEntry[OF_Y_OFFSET] = of_dy;

			int of_count = trafficEntry[COUNT_OF];
			of_count++;
			trafficEntry[COUNT_OF] = of_count;

			Log.Debug(P("Traffic Count - OF: %d counts"), of_count);
			opticalFlowCooldown();

			printData();
			beep(NUM_BEEPS_OF);
		}
	}

}

/**
* Check that the optical flow sensor is connected by polling the product code
*/
bool checkOpticalFlowConnection(){
	byte productID = flowSensor.read_register(ADNS3080_PRODUCT_ID);
	bool flowConnected = (productID == 0x17);

	return flowConnected;
}

/**
* Stop monitoring the optical flow sensor for a cooldown period.
* Meant to be used immediately following detection events to avoid
* multiple detections for the same event
*/
void opticalFlowCooldown(){
	stopOpticalFlow();
	timer.setTimeout(FLOW_COOLDOWN, resumeOpticalFlow);
}

/**
* Reset the traffic count for the optical flow sensor
*/
void resetFlowCount(){
	trafficEntry[COUNT_OF] = 0;
}


//////////////////////////////////////////////////////////////////////////
// Buzzer

/**
* Set up the buzzer for use
*/
void startBuzzer(){
	pinMode(BUZZER_PIN, OUTPUT);
	buzzerOff();
}

/**
* Beep the buzzer once.
* Uses a timeout event to turn the buzzer off
*/
void beep(){
	digitalWrite(BUZZER_PIN, BUZZER_ON);
	timer.setTimeout(BUZZER_BEEP_PERIOD, beepCheck);
}

/**
* Beep the buzzer multiple times.
* At low buzzer periods, multiple beeps sound more like a trill.
*/
void beep(int numBeeps){
	if (numBeeps > 0){
		beepCount = 1;
		maxBeeps = numBeeps;

		beep();
	}
}

/**
* Callback for beep - Check if the buzzer needs to beep again
*/
void beepCheck(){
	buzzerOff();

	if (beepCount < maxBeeps){
		beepCount++;
		timer.setTimeout(BUZZER_BEEP_QUIET_PERIOD, beep);
	}
}

/**
* Turn the buzzer off
*/
void buzzerOff(){
	digitalWrite(BUZZER_PIN, BUZZER_OFF);
}

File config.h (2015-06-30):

#include "Arduino.h"
#include <Logging.h>

// Comms settings
const long SERIAL_BAUD = 115200;
const int LOGGER_LEVEL = LOG_LEVEL_DEBUG;


// Pin assignments
const byte RANGEFINDER_AN_PIN = A0;
const byte RANGEFINDER_CONTROL_PIN = 8;
const byte RANGEFINDER_POWER_PIN = 0;

const byte PIR_MOTION_PIN = 6;
const byte PIR_CONTROL_PIN = 0;

const byte OPTICAL_FLOW_CHIP_SELECT_PIN = 9;

const byte BUZZER_PIN = 10;

const byte LIDAR_TRIGGER_PIN = 4;
const byte LIDAR_DETECT_PIN = 5;
const byte LIDAR_CONTROL_PIN = 0;

const byte YUN_HANDSHAKE_PIN = 7;


// Timer config
const int CHECK_MOTION_INTERVAL = 1000;
const int MOTION_COOLDOWN = 5000; // Time left for the PIR sensor to cool down after a detection in ms

const int CHECK_FLOW_INTERVAL = 200;
const int FLOW_COOLDOWN = 2000; // Optical flow detection cooldown in ms

const int CHECK_RANGE_INTERVAL = 200;
const int RANGE_DETECT_THRESHOLD = 50; // Minimum threshold for range detection in cm. (Target must move at least this much) 

const int LIDAR_CHECK_RANGE_INTERVAL = 200;
const int LIDAR_DETECT_THRESHOLD = 50;

const long LOG_TIMER_INTERVAL = 5000; // Time in between SD card log entries in ms.

const long XBEE_TRANSMIT_INTERVAL = 30000; // Time between XBee transmissions

// Misc

const int YUN_BOOT_DELAY = 5000; //Time to wait for Yun to boot up before checking the handshake
const byte COMMAND_CACHE_SIZE = 80;
const byte SEND_BUFFER_SIZE = 50;
const byte MIN_BASELINE_READS = 15; // Minimum number of reads needed to establish a baseline
const int BASELINE_READ_INTERVAL = 200; // Time between range baseline calibration reads
const int BASELINE_VARIANCE_THRESHOLD = 5; // Maximum acceptable range sensor baseline error in cm.

const int MOTION_INITIALISATION_TIME = 3000; // Time given for PIR sensor to calibrate in ms.
const byte MOTION_DETECTED = HIGH;

const byte OPTICAL_FLOW_MAX_RETRIES = 8;


// Commands
const char COMMAND_TERMINATOR = '$';
const char RESET_UVD_COUNT = 'q';
const char DISABLE_UVD = 'w';
const char ENABLE_UVD = 'e';

// Buzzer
const int BUZZER_BEEP_PERIOD = 10; // Beep length in ms
const int BUZZER_BEEP_QUIET_PERIOD = 50; // Beep 'downtime' in ms
const bool BUZZER_ON = HIGH;
const bool BUZZER_OFF = LOW;
const byte NUM_BEEPS_UVD = 2;
const byte NUM_BEEPS_PIR = 1;
const byte NUM_BEEPS_LIDAR = 3;
const byte NUM_BEEPS_OF = 0;

// JSON string tags
const char ID[] = "id";
const char VERSION[] = "version";
const char COUNT_UVD[] = "count_uvd";
const char UVD_RANGE[] = "uvd_range";
const char COUNT_PIR[] = "count_pir";
const char PIR_STATUS[] = "pir_status";
const char COUNT_OF[] = "count_of";
const char OF_X_OFFSET[] = "of_dx";
const char OF_Y_OFFSET[] = "of_dy";
const char OF_STATUS[] = "of_status";
const char OF_CONNECTED[] = "of_connected";
const char COUNT_LIDAR[] = "count_lidar";
const char LIDAR_RANGE[] = "lidar_range";

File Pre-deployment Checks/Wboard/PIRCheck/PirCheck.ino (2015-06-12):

#include <ProgmemString.h>
#include <SimpleTimer.h>
#include <Logging.h>
#include "config.h"

SimpleTimer timer;
int motionTimerID = -1;

bool motionDetected;
int motionCount;
long detectionStart;

void setup(){
	Log.Init(LOGGER_LEVEL, SERIAL_BAUD);
	Log.Info(P("Traffic Counter - PIR Test"));

	detectionStart = 0;
	startMotionDetector();

}

void loop()
{

	timer.run();

}


//////////////////////////////////////////////////////////////////////////
// Motion Detector

/**
* startMotionDetector
*
* Start the PIR motion sensor for motion detections
*/
void startMotionDetector(){
	enableMotion();

	pinMode(PIR_MOTION_PIN, INPUT);

	Log.Debug(P("Calibrating motion sensor - wait %d ms"), MOTION_INITIALISATION_TIME);
	delay(MOTION_INITIALISATION_TIME);
	motionDetected = false;

	motionTimerID = timer.setInterval(CHECK_MOTION_INTERVAL, getMotion);
	Log.Debug(P("Motion started"));
}

/**
* enableMotion
*
* Turn on the motion sensor
*/
void enableMotion(){
	pinMode(PIR_CONTROL_PIN, OUTPUT);
	digitalWrite(PIR_CONTROL_PIN, HIGH);
}

/**
* stopMotionDetector
*
* Stop checking the motion detector
*/
void stopMotionDetector(){
	timer.deleteTimer(motionTimerID);
	disableMotion();

	Log.Debug(P("Motion sensor stopped"));
}

/**
* Check the PIR sensor for detected movement
* The sensor will output HIGH when motion is detected.
* Detections will hold the detection status HIGH until the cool-down has lapsed (default: 60s)
*
* Returns:
*	True if motion has been detected recently
*/
void getMotion(){

	// Check the sensor
	if (digitalRead(PIR_MOTION_PIN) == MOTION_DETECTED){
		if (motionDetected == false){
			detectionStart = millis();
		}
		motionDetected = true;
		

	}
	else{
		// No alarm; is fine
		motionDetected = false;
		detectionStart = millis();

	}

	long timeSinceDetection = millis() - detectionStart;
	Log.Info(P("Motion detected: %T - %l ms"), motionDetected, timeSinceDetection);
}

/**
* Temporarily pause checking the PIR motion sensor
*/
void motionCoolDown(){
	timer.deleteTimer(motionTimerID);
	motionTimerID = -1;
	timer.setTimeout(MOTION_COOLDOWN, resumeMotionDetection);
}

/**
* Start polling the PIR motion sensor
*/
void resumeMotionDetection(){
	motionTimerID = timer.setInterval(CHECK_MOTION_INTERVAL, getMotion);
}

/**
* resetMotionCount
*
* Reset the number of motion detections
*/
void resetMotionCount(){
	motionCount = 0;
}

/**
* disableMotion
*
* Turn off the motion sensor
*/
void disableMotion(){
	digitalWrite(PIR_CONTROL_PIN, LOW);
}

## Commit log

2015-05-05 Added ultrasonic detection
    + Ultrasonic detection now works
    + Serial commands added to control ultrasonic rangefinder
    + Tested ultrasonic code
    + Motion code added
2015-05-05 Data storage and transmission added
    +SD card formatting fixed
    + XBee transmission added (untested)
    [TrafficCounter.ino, config.h]
2015-05-27 Merged traffic counter projects
    + Folder structure updated
    + Buzzers added to latest code edition
    + Data storage locations make sense
    [Pole mount top.skp, Pole mount top.stl, Pole mount topv2.skp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]
2015-05-27 Added some CAD graphics
    [Desk clamp - holder.stl, Pole mount top.skp, Pole mount top.stl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]
2015-05-29 Added in option for Lidar sensing
    + Lidar basically uses the same logic as the ultrasonic rangefinder for
    detection
    + Test placeholders added
2015-06-09 Added Test 04 files
    - Added Lidar check script
    - About to switch target to Yun
    [Traffic Count - Test 4 - 2015.06.02 1617.xlsx]
2015-06-12 Adapted arduino code for Yun
